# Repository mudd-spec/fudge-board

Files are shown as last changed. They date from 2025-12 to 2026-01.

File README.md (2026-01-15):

# fudge board
------ 
## Important!
This board charges batteries but does NOT run off batteries connected to the BAT and GND terminals. I plan to make a revised version where this is changed.

This is an RP2040 dev board created based off the <a href="https://github.com/KaiPereira/build-a-devboard">guide</a> from Blueprint at Hackclub!

### Features
- RP2040 Chip
- 12MHz Crystal Oscillator
- Many GPIO Pins
- a 1 Cell Lipo/Li-ion Battery Charger
- LED connected to GPIO
- USB-C
- 16MB of Flash Memory
- LDO Power Regulator

#### KiCad
The entire board was made with this software! The pictures below are taken from KiCad!

<strong>Schematic</strong>



<strong>PCB</strong>



#### JLCPCB
Here is a sample of what manufacturing the board might cost.

<strong>BOM</strong>

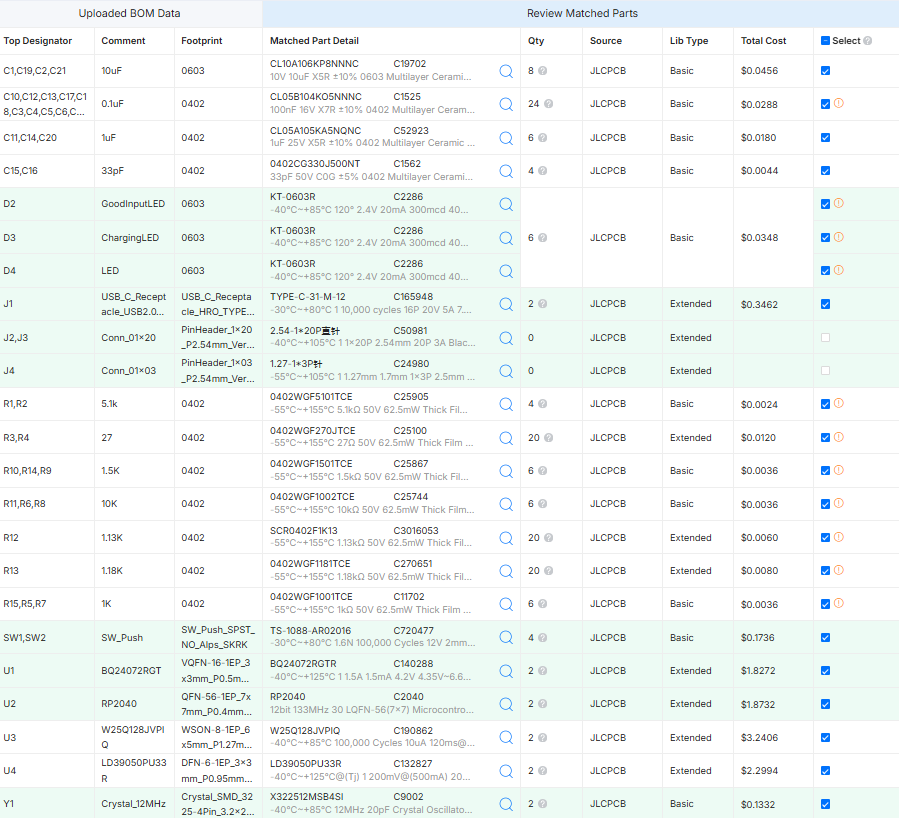
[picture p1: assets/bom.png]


<strong>Final Price</strong>

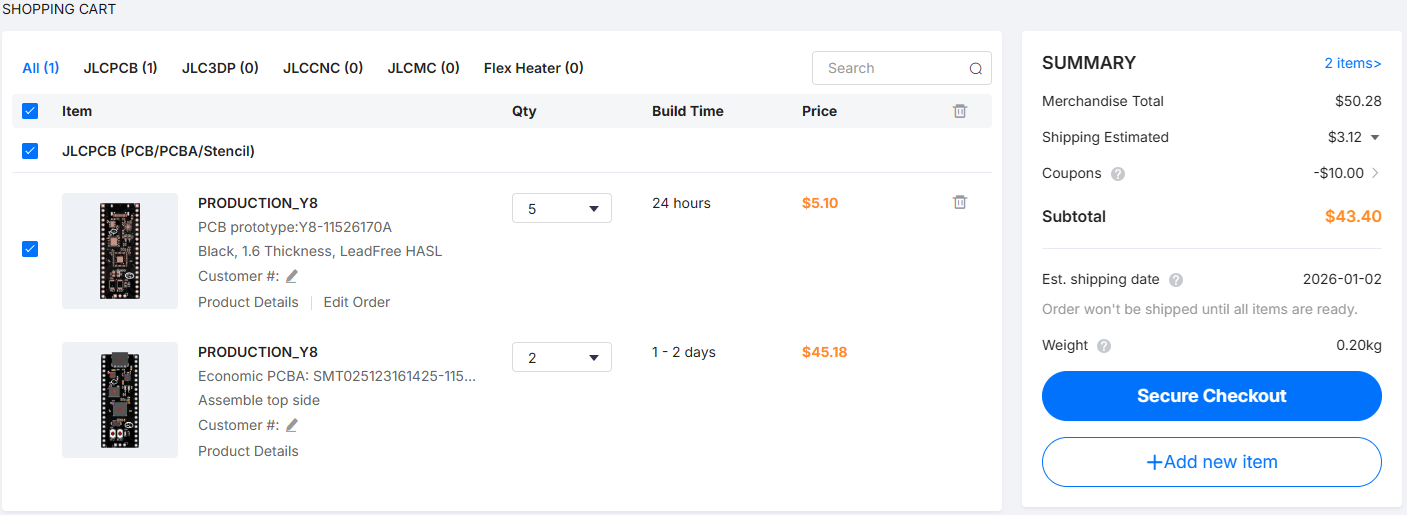
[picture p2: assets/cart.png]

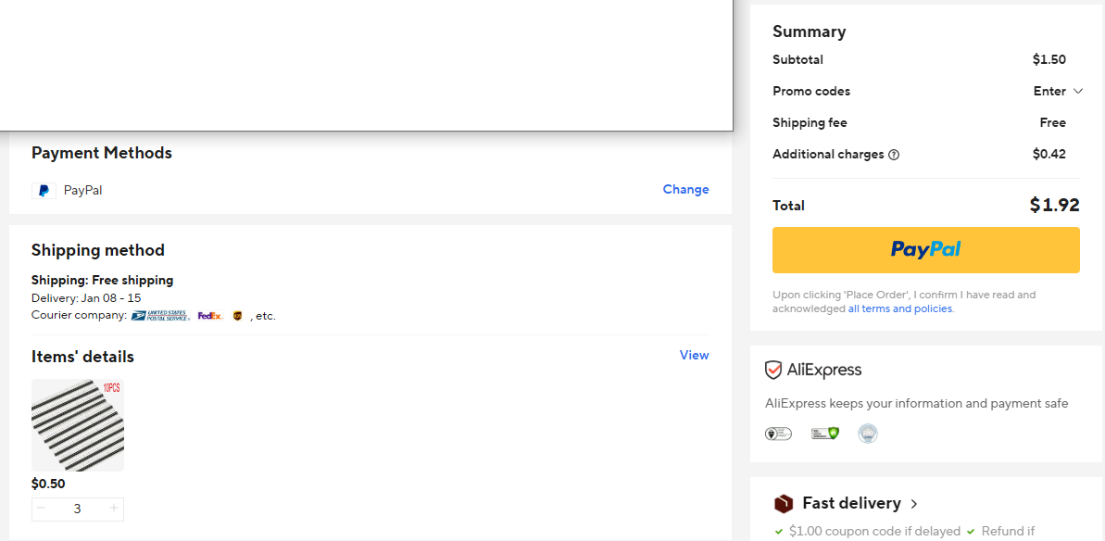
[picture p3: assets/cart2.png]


#### Excalidraw
All silkscreen drawings were made with this handy website.
#### Extra
From this project I learned a lot more about how common communication interfaces like SPI, UART, and I2C work. I quickly picked up on electronics basics such as the theory behind decoupling capacitors, pull-up/pull-down resistors, and common electronics components (flash memory ics, crystal oscillators, etc.). I hope with this knowledge, I can continue on to put together a little single board computer, like the common Raspberry Pi.

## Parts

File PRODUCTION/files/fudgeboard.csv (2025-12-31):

Designator | Footprint | Quantity | Value | LCSC Part #
C1, C19, C2, C21 | 0603 | 4 | 10uF
C10, C12, C13, C17, C18, C3, C4, C5, C6, C7, C8, C9 | 0402 | 12 | 0.1uF
C11, C14, C20 | 0402 | 3 | 1uF
C15, C16 | 0402 | 2 | 33pF
D2 | 0603 | 1 | Good Input LED
D3 | 0603 | 1 | Charging LED
D4 | 0603 | 1 | LED
J1 | USB_C_Receptacle_HRO_TYPE-C-31-M-12 | 1 | USB_C_Receptacle_USB2.0_14P
J2, J3 | PinHeader_1x20_P2.54mm_Vertical | 2 | Conn_01x20
J4 | PinHeader_1x03_P2.54mm_Vertical | 1 | Conn_01x03
R1, R2 | 0402 | 2 | 5.1k
R10, R14, R9 | 0402 | 3 | 1.5K
R11, R6, R8 | 0402 | 3 | 10K
R12 | 0402 | 1 | 1.13K
R13 | 0402 | 1 | 1.18K
R15, R5, R7 | 0402 | 3 | 1K
R3, R4 | 0402 | 2 | 27
SW1, SW2 | SW_Push_SPST_NO_Alps_SKRK | 2 | SW_Push
TP1 | TestPoint_Pad_2.5x2.5mm | 1 | BAT+
TP2 | TestPoint_Pad_2.5x2.5mm | 1 | GND
U1 | VQFN-16-1EP_3x3mm_P0.5mm_EP1.6x1.6mm | 1 | BQ24072RGT
U2 | QFN-56-1EP_7x7mm_P0.4mm_EP3.2x3.2mm | 1 | RP2040
U3 | WSON-8-1EP_6x5mm_P1.27mm_EP3.4x4mm | 1 | W25Q128JVPIQ
U4 | DFN-6-1EP_3x3mm_P0.95mm_EP1.7x2.6mm | 1 | LD39050PU33R
Y1 | Crystal_SMD_3225-4Pin_3.2x2.5mm | 1 | Crystal_12MHz

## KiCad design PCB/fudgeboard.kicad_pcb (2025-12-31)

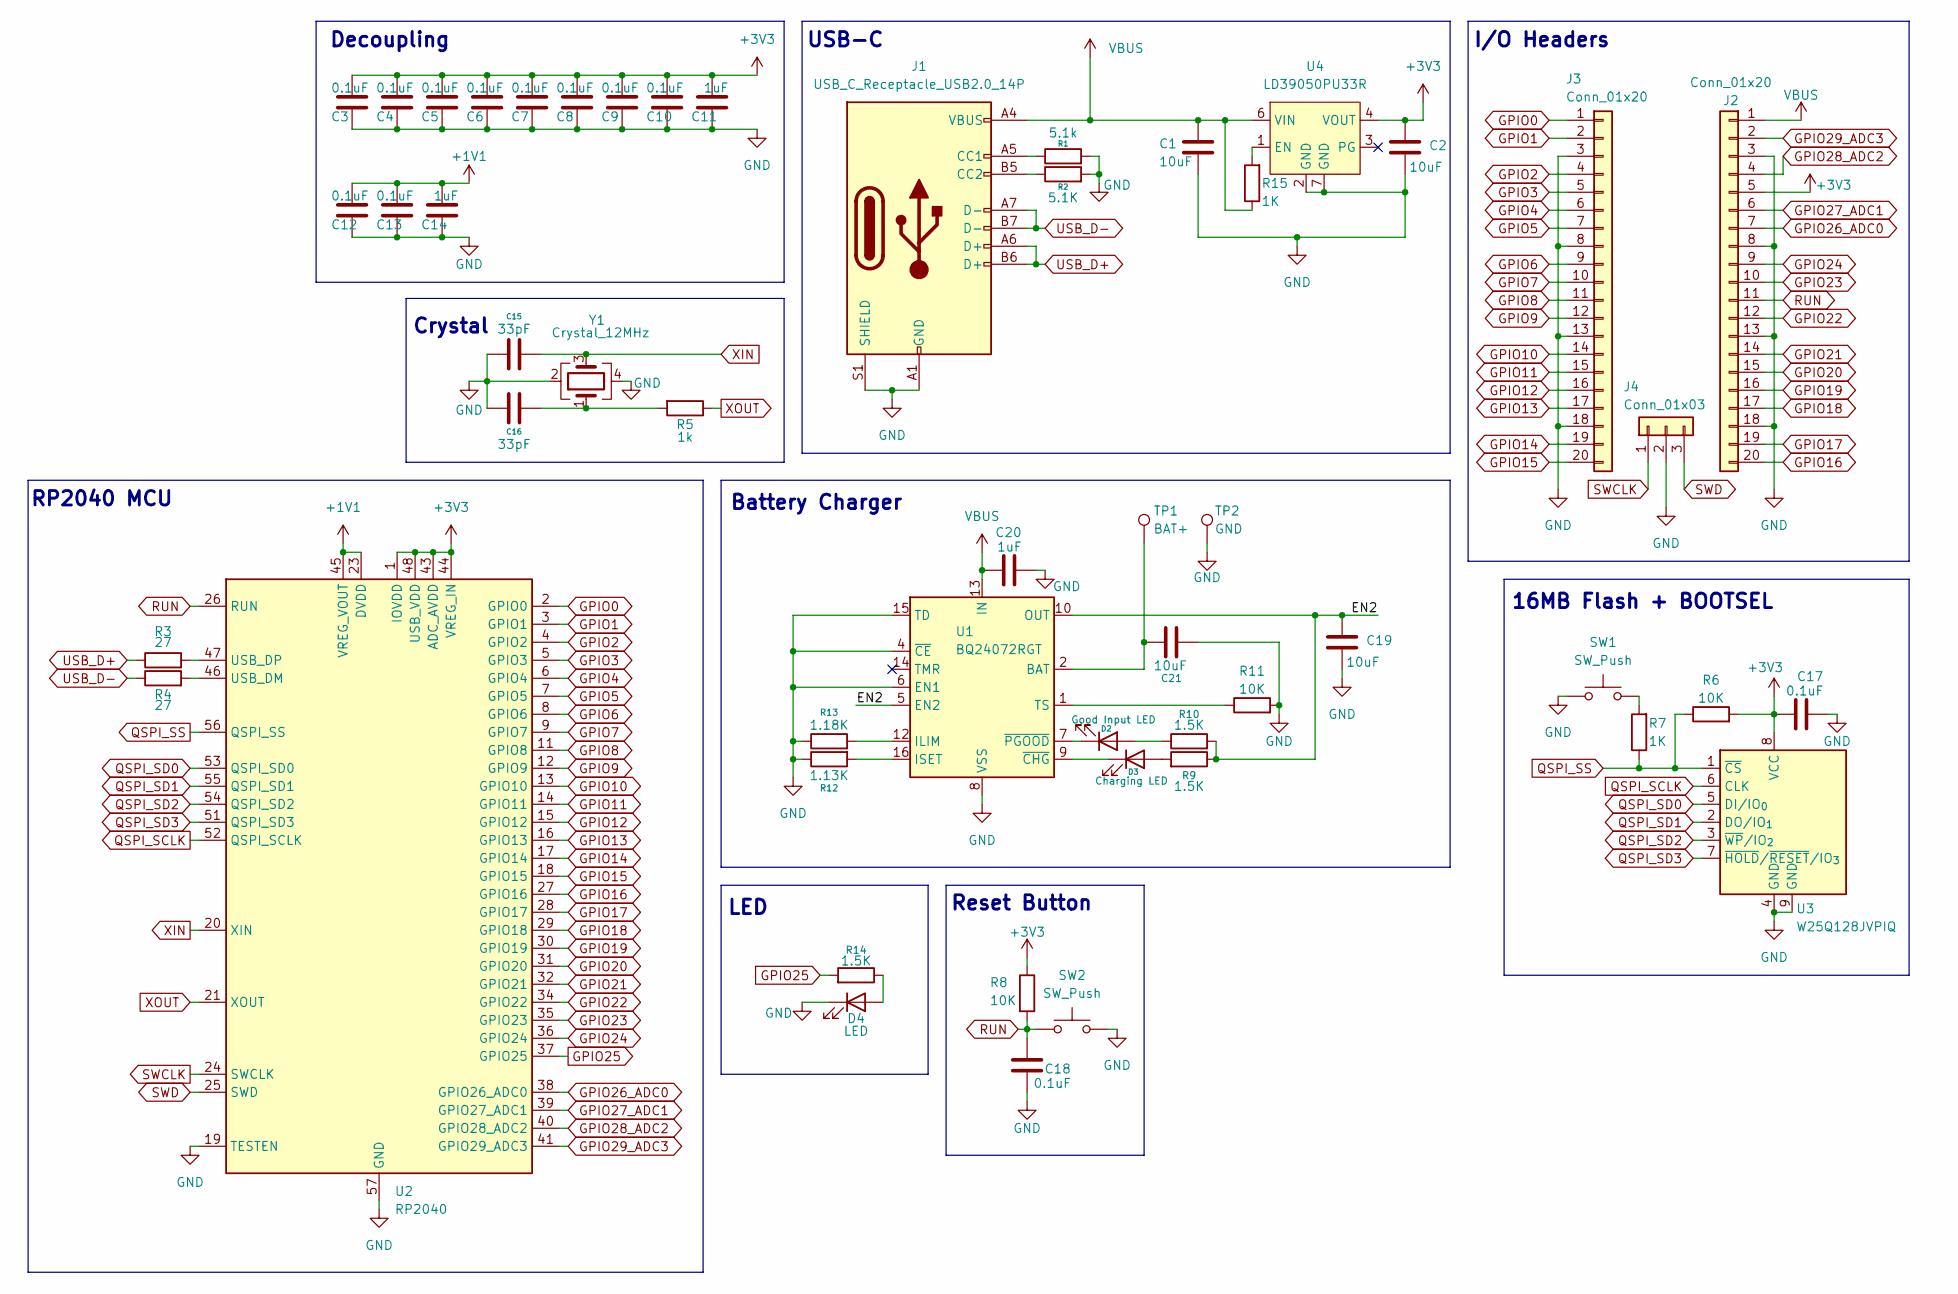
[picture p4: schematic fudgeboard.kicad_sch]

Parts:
C1, C2, C19, C21: 10uF; C_0603_1608Metric
C3, C4, C5, C6, C7, C8, C9, C10, C12, C13, C17, C18: 0.1uF; C_0402_1005Metric
C11, C14, C20: 1uF; C_0402_1005Metric
C15, C16: 33pF; C_0402_1005Metric
D2: Good Input LED; LED_0603_1608Metric
D3: Charging LED; LED_0603_1608Metric
D4: LED; LED_0603_1608Metric
J1: USB_C_Receptacle_USB2.0_14P; USB_C_Receptacle_HRO_TYPE-C-31-M-12
J2, J3: Conn_01x20; PinHeader_1x20_P2.54mm_Vertical
J4: Conn_01x03; PinHeader_1x03_P2.54mm_Vertical
R1: 5.1k; R_0402_1005Metric
R2: 5.1K; R_0402_1005Metric
R3, R4: 27; R_0402_1005Metric
R5: 1k; R_0402_1005Metric
R6, R8, R11: 10K; R_0402_1005Metric
R7, R15: 1K; R_0402_1005Metric
R9, R10, R14: 1.5K; R_0402_1005Metric
R12: 1.13K; R_0402_1005Metric
R13: 1.18K; R_0402_1005Metric
SW1, SW2: SW_Push; SW_Push_SPST_NO_Alps_SKRK
TP1: BAT+; TestPoint_Pad_2.5x2.5mm
TP2: GND; TestPoint_Pad_2.5x2.5mm
U1: BQ24072RGT; VQFN-16-1EP_3x3mm_P0.5mm_EP1.6x1.6mm
U2: RP2040; QFN-56-1EP_7x7mm_P0.4mm_EP3.2x3.2mm
U3: W25Q128JVPIQ; WSON-8-1EP_6x5mm_P1.27mm_EP3.4x4mm
U4: LD39050PU33R; DFN-6-1EP_3x3mm_P0.95mm_EP1.7x2.6mm
Y1: Crystal_12MHz; Crystal_SMD_3225-4Pin_3.2x2.5mm

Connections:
+1V1: C12.1, C13.1, C14.1, U2.23 (DVDD), U2.45 (VREG_VOUT), U2.50 (DVDD)
+3V3: C2.1, C3.1, C4.1, C5.1, C6.1, C7.1, C8.1, C9.1, C10.1, C11.1, C17.1, J2.5, R6.2, R8.1, U2.1 (IOVDD), U2.10 (IOVDD), U2.22 (IOVDD), U2.33 (IOVDD), U2.42 (IOVDD), U2.43 (ADC_AVDD), U2.44 (VREG_IN), U2.48 (USB_VDD), U2.49 (IOVDD), U3.8 (VCC), U4.4 (VOUT)
/EN2: C19.1, R9.1, R10.2, U1.5 (EN2), U1.10 (OUT), U1.11 (OUT)
GND: C1.2, C2.2, C3.2, C4.2, C5.2, C6.2, C7.2, C8.2, C9.2, C10.2, C11.2, C12.2, C13.2, C14.2, C15.1, C16.1, C17.2, C18.2, C19.2, C20.1, C21.1, D4.1 (K), J1.A1 (GND), J1.A12 (GND), J1.B1 (GND), J1.B12 (GND), J1.S1 (SHIELD), J2.3, J2.8, J2.13, J2.18, J3.3, J3.8, J3.13, J3.18, J4.2, R1.2, R2.2, R11.2, R12.1, R13.1, SW1.1, SW2.2, TP2.1, U1.4 (~CE), U1.6 (EN1), U1.8 (VSS), U1.15 (TD), U1.17 (VSS), U2.19 (TESTEN), U2.57 (GND), U3.4 (GND), U3.9 (GND), U4.2 (GND), U4.7 (GND), Y1.2, Y1.4
GPIO0: J3.1, U2.2 (GPIO0)
GPIO1: J3.2, U2.3 (GPIO1)
GPIO2: J3.4, U2.4 (GPIO2)
GPIO3: J3.5, U2.5 (GPIO3)
GPIO4: J3.6, U2.6 (GPIO4)
GPIO5: J3.7, U2.7 (GPIO5)
GPIO6: J3.9, U2.8 (GPIO6)
GPIO7: J3.10, U2.9 (GPIO7)
GPIO8: J3.11, U2.11 (GPIO8)
GPIO9: J3.12, U2.12 (GPIO9)
GPIO10: J3.14, U2.13 (GPIO10)
GPIO11: J3.15, U2.14 (GPIO11)
GPIO12: J3.16, U2.15 (GPIO12)
GPIO13: J3.17, U2.16 (GPIO13)
GPIO14: J3.19, U2.17 (GPIO14)
GPIO15: J3.20, U2.18 (GPIO15)
GPIO16: J2.20, U2.27 (GPIO16)
GPIO17: J2.19, U2.28 (GPIO17)
GPIO18: J2.17, U2.29 (GPIO18)
GPIO19: J2.16, U2.30 (GPIO19)
GPIO20: J2.15, U2.31 (GPIO20)
GPIO21: J2.14, U2.32 (GPIO21)
GPIO22: J2.12, U2.34 (GPIO22)
GPIO23: J2.10, U2.35 (GPIO23)
GPIO24: J2.9, U2.36 (GPIO24)
GPIO25: R14.2, U2.37 (GPIO25)
GPIO26_ADC0: J2.7, U2.38 (GPIO26_ADC0)
GPIO27_ADC1: J2.6, U2.39 (GPIO27_ADC1)
GPIO28_ADC2: J2.4, U2.40 (GPIO28_ADC2)
GPIO29_ADC3: J2.2, U2.41 (GPIO29_ADC3)
unnamed: C16.2, R5.2, Y1.1
unnamed: C21.2, TP1.1, U1.2 (BAT), U1.3 (BAT)
unnamed: D2.2 (A), R10.1
unnamed: D2.1 (K), U1.7 (~PGOOD)
unnamed: D3.2 (A), R9.2
unnamed: D3.1 (K), U1.9 (~CHG)
unnamed: D4.2 (A), R14.1
unnamed: J1.A5 (CC1), R1.1
unnamed: J1.B5 (CC2), R2.1
unnamed: R7.2, SW1.2
unnamed: R13.2, U1.12 (ILIM)
unnamed: R12.2, U1.16 (ISET)
unnamed: R11.1, U1.1 (TS)
unnamed: R4.2, U2.46 (USB_DM)
unnamed: R3.2, U2.47 (USB_DP)
unnamed: R15.2, U4.1 (EN)
QSPI_SCLK: U2.52 (QSPI_SCLK), U3.6 (CLK)
QSPI_SD0: U2.53 (QSPI_SD0), U3.5 (DI/IO_{0})
QSPI_SD1: U2.55 (QSPI_SD1), U3.2 (DO/IO_{1})
QSPI_SD2: U2.54 (QSPI_SD2), U3.3 (~WP/IO_{2})
QSPI_SD3: U2.51 (QSPI_SD3), U3.7 (~HOLD/~RESET/IO_{3})
QSPI_SS: R6.1, R7.1, U2.56 (QSPI_SS), U3.1 (~CS)
RUN: C18.1, J2.11, R8.2, SW2.1, U2.26 (RUN)
SWCLK: J4.1, U2.24 (SWCLK)
SWD: J4.3, U2.25 (SWD)
USB_D+: J1.A6 (D+), J1.B6 (D+), R3.1
USB_D-: J1.A7 (D-), J1.B7 (D-), R4.1
VBUS: C1.1, C20.2, J1.A4 (VBUS), J1.A9 (VBUS), J1.B4 (VBUS), J1.B9 (VBUS), J2.1, R15.1, U1.13 (IN), U4.6 (VIN)
XIN: C15.2, U2.20 (XIN), Y1.3
XOUT: R5.1, U2.21 (XOUT)

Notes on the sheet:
Crystal
RP2040 MCU
I/O Headers
Reset Button
Decoupling
USB-C
16MB Flash + BOOTSEL
LED
Battery Charger

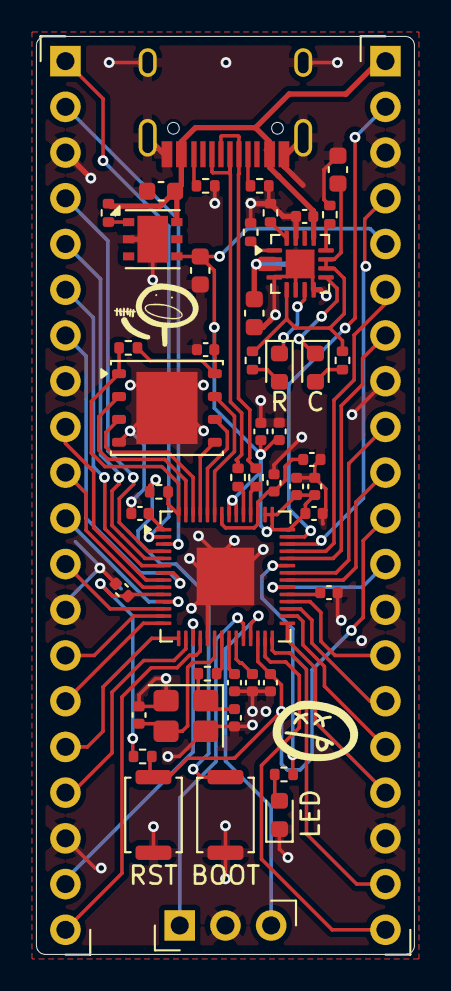
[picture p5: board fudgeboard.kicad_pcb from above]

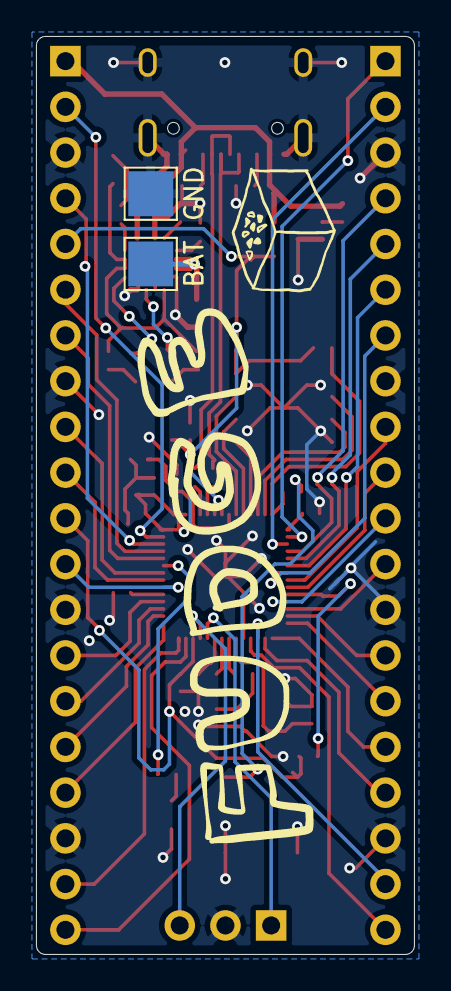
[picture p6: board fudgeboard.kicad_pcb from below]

Board: 2 copper layers, 21.0 x 51.0 mm, 52 parts (2 on the bottom side), 64 nets.
